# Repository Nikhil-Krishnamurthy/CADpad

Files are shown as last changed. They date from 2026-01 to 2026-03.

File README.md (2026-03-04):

# CADpad
Macropad designed from scratch for cad, media, and coding. Along with a custom script to run badapple on the oled screen!  
Note that the pcb has the scl and sca pins mixed up on it, I just cut the traces and ran a wire around it.  
  
Key Features  
Macropad with 11 reprogrammable keys  
oled screen that displays layers and animations  
rotary encoder that interfaces with computer  
interface with the computer for input and output  
And of course, it can run bad apple  

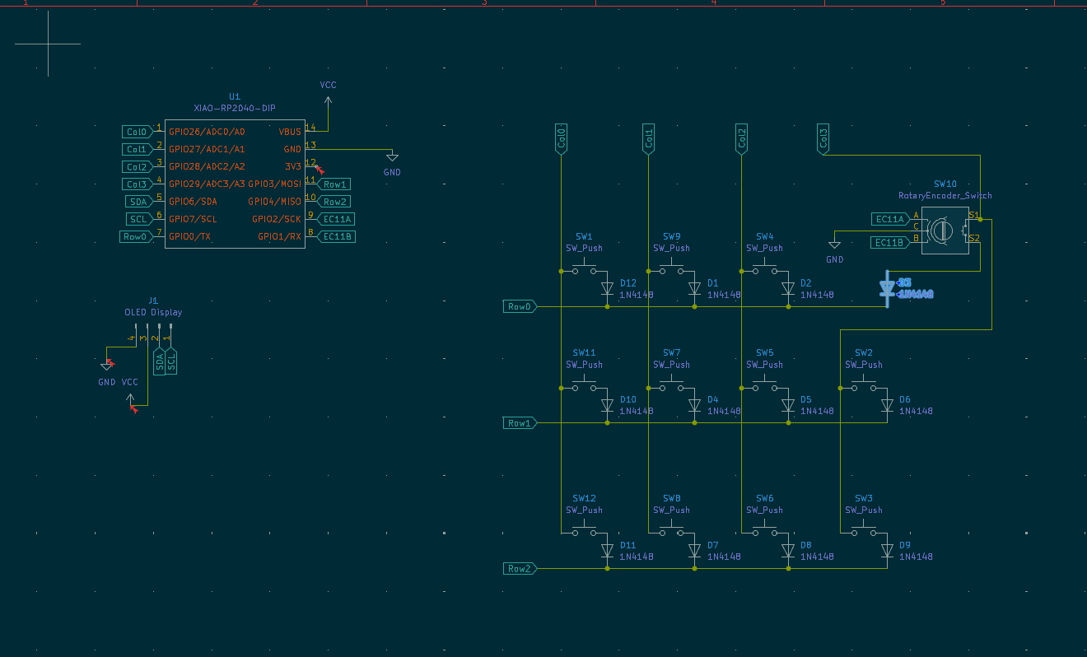
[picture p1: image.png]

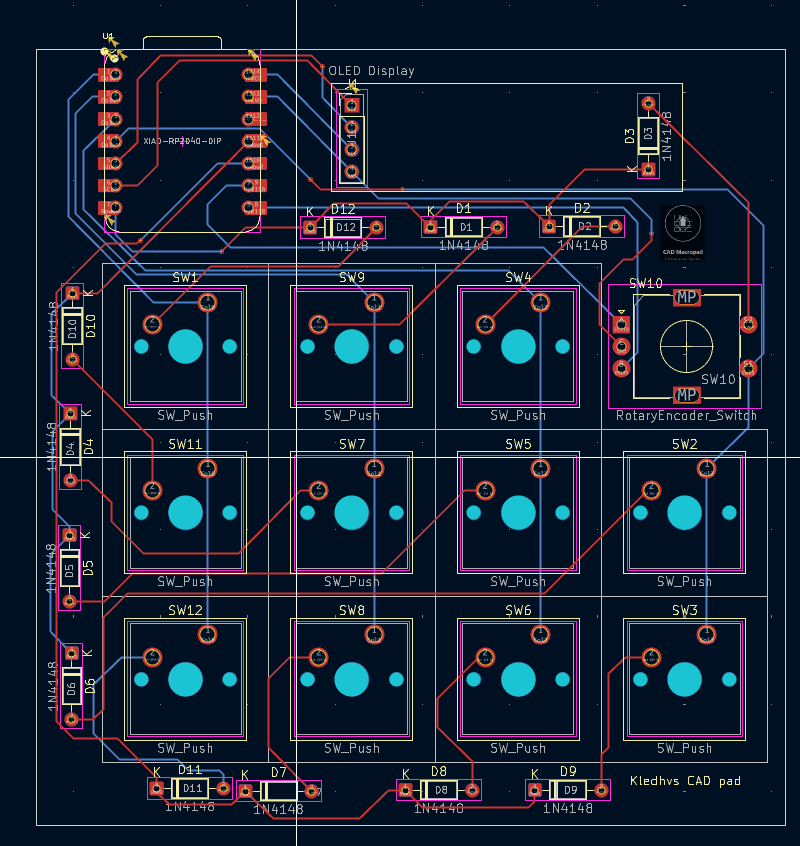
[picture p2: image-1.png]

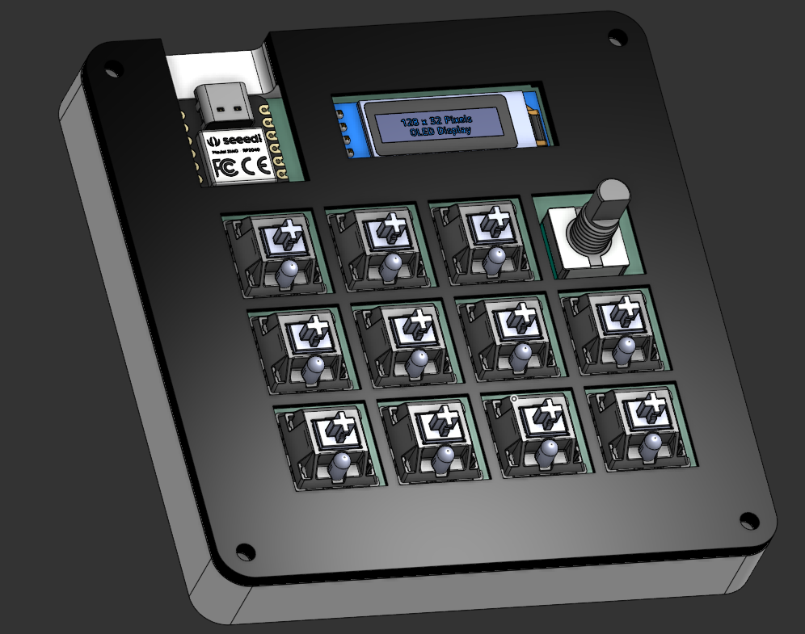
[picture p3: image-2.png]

BOM  
12x 1n4148 Diodes  
1x EC11 Encoders  
1x 0.91 in OLED display  
11x DSA keycaps  
11x Cherry MX Keycaps  
1x XIAO RP2040  
1X Case (3d Printed)  
4x M3 16mm screws  
4x M3x5mmx4mm Heat Inserts

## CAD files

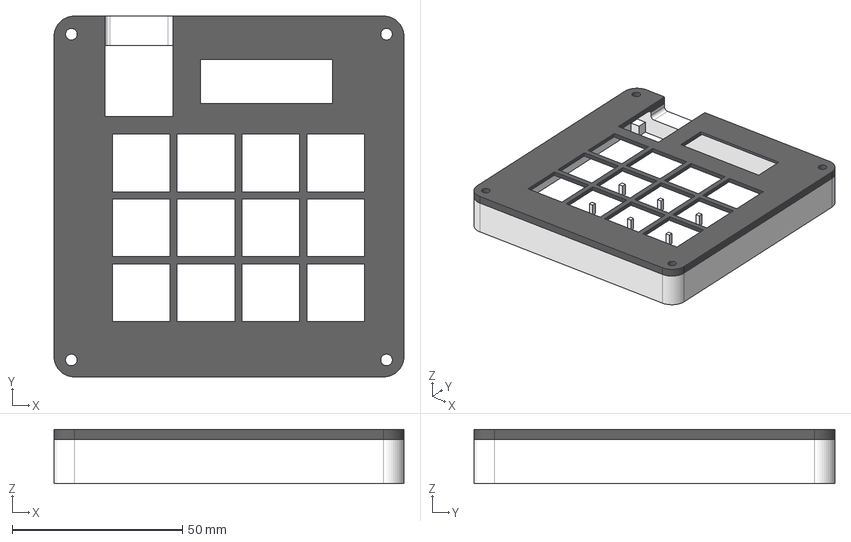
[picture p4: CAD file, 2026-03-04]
CAD/CadPad.step
102.8 x 106.0 x 16.0 mm

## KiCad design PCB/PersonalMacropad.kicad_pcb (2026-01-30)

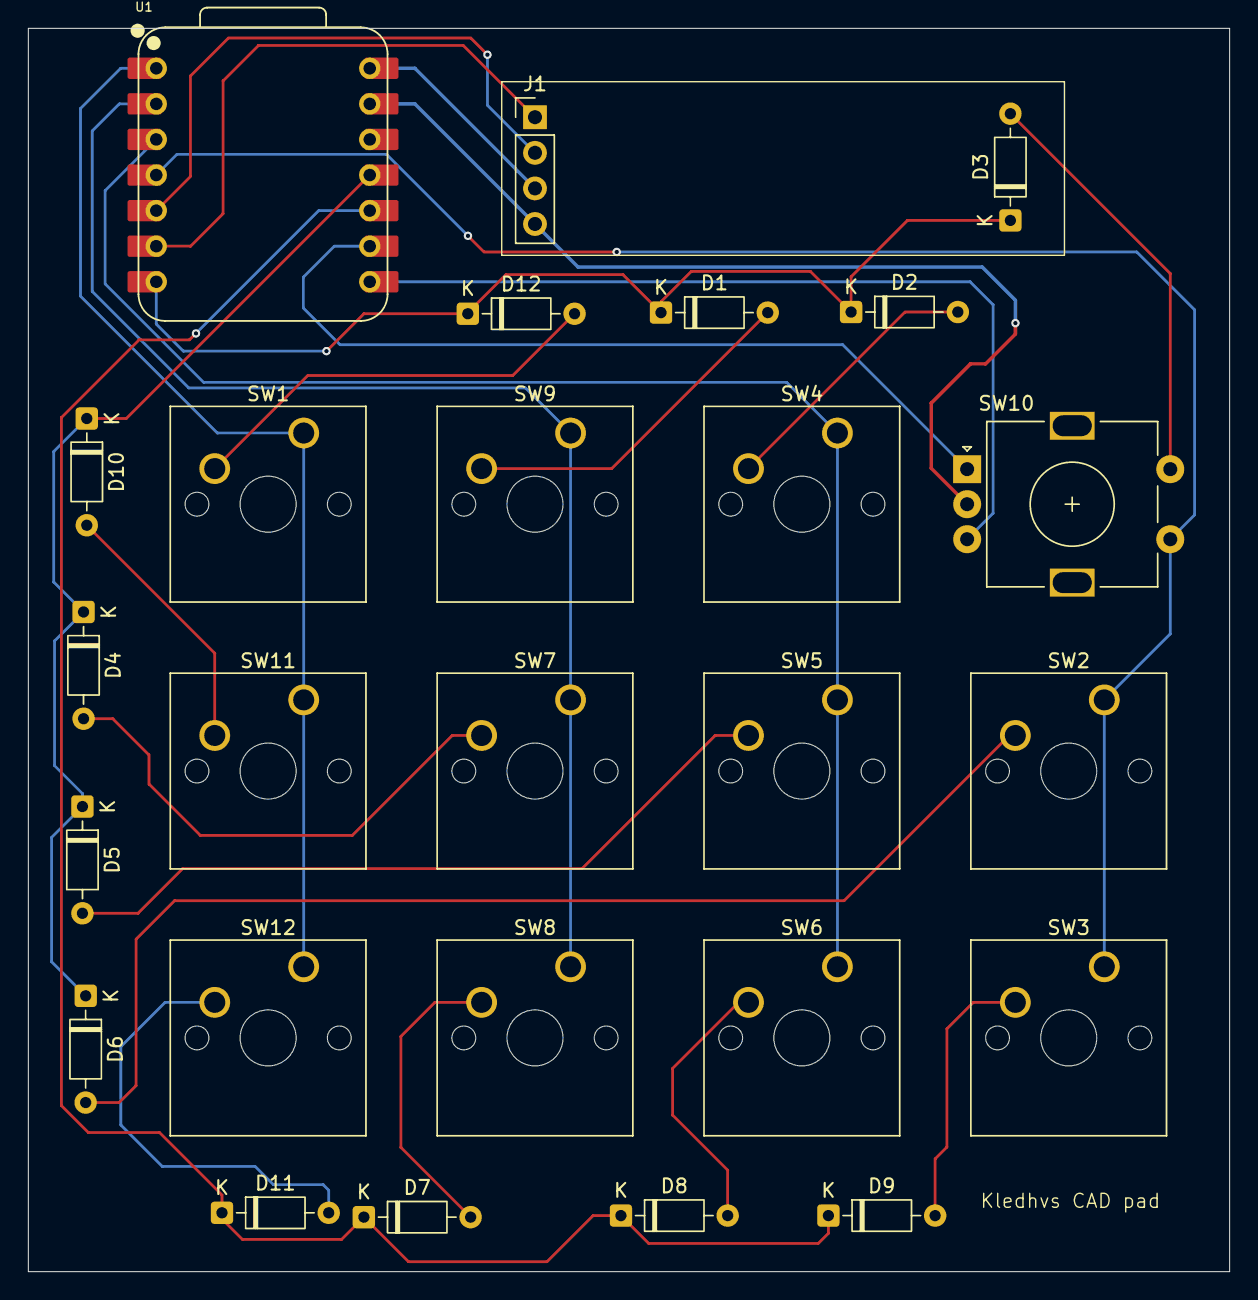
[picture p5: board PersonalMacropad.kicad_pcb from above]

Board: 2 copper layers, 85.7 x 88.8 mm, 26 parts (0 on the bottom side), 25 nets.

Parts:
D1, D2, D3, D4, D5, D6, D7, D8, D9, D10, D11, D12: 1N4148; D_DO-35_SOD27_P7.62mm_Horizontal
J1: OLED Display; PinHeader_1x04_P2.54mm_Vertical
SW1, SW2, SW3, SW4, SW5, SW6, SW7, SW8, SW9, SW11, SW12: SW_Push; SW_Cherry_MX_1.00u_PCB
SW10: RotaryEncoder_Switch; RotaryEncoder_Alps_EC11E-Switch_Vertical_H20mm
U1: XIAO-RP2040-DIP

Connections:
Col0: SW1.1, SW11.1, SW12.1, U1.1 (GPIO26/ADC0/A0)
Col1: SW7.1, SW8.1, SW9.1, U1.2 (GPIO27/ADC1/A1)
Col2: SW4.1, SW5.1, SW6.1, U1.3 (GPIO28/ADC2/A2)
Col3: SW2.1, SW3.1, SW10.S1, U1.4 (GPIO29/ADC3/A3)
EC11A: SW10.A, U1.9 (GPIO2/SCK)
EC11B: SW10.B, U1.8 (GPIO1/RX)
GND: J1.4, SW10.C, U1.13 (GND)
unnamed: D1.2 (A), SW9.2
unnamed: D2.2 (A), SW4.2
unnamed: D3.2 (A), SW10.S2
unnamed: D4.2 (A), SW7.2
unnamed: D5.2 (A), SW5.2
unnamed: D6.2 (A), SW2.2
unnamed: D7.2 (A), SW8.2
unnamed: D8.2 (A), SW6.2
unnamed: D9.2 (A), SW3.2
unnamed: D10.2 (A), SW11.2
unnamed: D11.2 (A), SW12.2
unnamed: D12.2 (A), SW1.2
Row0: D1.1 (K), D2.1 (K), D3.1 (K), D12.1 (K), U1.7 (GPIO0/TX)
Row1: D4.1 (K), D5.1 (K), D6.1 (K), D10.1 (K), U1.11 (GPIO3/MOSI)
Row2: D7.1 (K), D8.1 (K), D9.1 (K), D11.1 (K), U1.10 (GPIO4/MISO)
SCL: J1.1, U1.6 (GPIO7/SCL)
SDA: J1.2, U1.5 (GPIO6/SDA)
VCC: J1.3, U1.14 (VBUS)

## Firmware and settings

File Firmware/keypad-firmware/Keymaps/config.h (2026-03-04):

#pragma once

#define I2C_DRIVER I2CD1
#define I2C1_SDA_PIN GP6
#define I2C1_SCL_PIN GP7

#define OLED_BRIGHTNESS 90
#define OLED_TIMEOUT 5000
#define OLED_UPDATE_INTERVAL 100
#define OLED_DISPLAY_ADDRESS 0x3C
#define OLED_BOOT_TIMEOUT 100

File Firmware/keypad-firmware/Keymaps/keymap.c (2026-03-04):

// Copyright 2023 Nico Stuhlmueller (@ThePurox)
// SPDX-License-Identifier: GPL-2.0-or-later
#include QMK_KEYBOARD_H
#include <string.h>

#define LAYOUT_MACROPAD(\
  k00, k01, k02, k03, \
  k10, k11, k12, k13, \
  k20, k21, k22, k23\
) {\
  { k00, k01, k02, k03 }, \
  { k10, k11, k12, k13 }, \
  { k20, k21, k22, k23 }  \
}

enum layer_names{
    __MEDIA,
    __CAD,
    __OVERLAY,
    __CODE,
    __OLED,
};

#define COPY LCTL(KC_C)
#define PSTE LCTL(KC_V)
#define UNDO LCTL(KC_Z)

#define D_MUTE LCTL(KC_F13)
#define D_DEAF LCTL(KC_F14)
    
#define EXTRUDE LSFT(KC_E)
#define SKETCH LSFT(KC_S)
#define REVOLVE LSFT(KC_W)
#define FILLET LSFT(KC_F)
#define STEAM LSFT(KC_TAB)
#define DISCORD LSFT(KC_NUBS)

#define KILLER LCTL(LSFT(KC_ESC))
#define PERFORMANCE LCTL(KC_F3)

#define MAX_OLED_BRIGHTNESS 255
#define HIGH_OLED_BRIGHTNESS 130
#define MEDIUM_OLED_BRIGHTNESS 90
#define LOW_OLED_BRIGHTNESS 65
#define MIN_OLED_BRIGHTNESS 1

#define LAYER_CYCLE_START 0
#define LAYER_CYCLE_END 4

#define IMPORT_BIN(sect, file, sym) \
    asm(".section " #sect "\n" \
        ".balign 4\n" \
        ".global " #sym "\n" \
        #sym ":\n" \
        ".incbin \"" file "\"\n" \
        ".global _sizeof_" #sym "\n" \
        ".set _sizeof_" #sym ", . - " #sym "\n" \
        ".balign 4\n" \
        ".section \".text\"\n")

IMPORT_BIN(".rodata", "badapple.bin", badapple_data);

extern const uint8_t badapple_data[];
extern const char _sizeof_badapple_data[];

#define TOTAL_FRAMES 3194
#define FRAME_DELAY 100

static uint32_t oled_timer = 0;
static uint16_t frame_index = 0;

enum keycodes {
  KC_CYCLE_LAYERS = QK_USER,
  CK_CYCLE_LAYERS,
  ANIMATION_TOGGLE,
  OLED_BRIGHTNESS_UP,
  OLED_BRIGHTNESS_DOWN,
  OLED_BRIGHTNESS_DEFAULT,
  OLED_ON_OFF,
  ANIMATION_ONCE,
  PRINT_LN,
  PRINT,
  LOOP_STATEMENT,
  IF_STATEMENT,
  ELSE_IF_STATEMENT,
  ELSE_STATEMENT,
};

bool animation_value = false;
uint8_t loop_value = 0;
uint8_t brightness_layer = 2;

void brightness_picker(int level){
  switch(level){
    case 0:
      oled_set_brightness(MAX_OLED_BRIGHTNESS);
      break;
    case 1:
      oled_set_brightness(HIGH_OLED_BRIGHTNESS);
      break;
    case 2:
      oled_set_brightness(MEDIUM_OLED_BRIGHTNESS);
      break;
    case 3:
      oled_set_brightness(LOW_OLED_BRIGHTNESS);
      break;
    case 4:
      oled_set_brightness(MIN_OLED_BRIGHTNESS);
      break;
    default:
      break;
  }
}

void render_bad_apple(void) {
    if (timer_elapsed32(oled_timer) > FRAME_DELAY) {
        oled_timer = timer_read32();

        const uint8_t* frame_ptr = badapple_data + (frame_index * 512);

        // --- Fix 2: Added (const char*) cast to satisfy the compiler ---
        oled_write_raw_P((const char*)frame_ptr, 512);

        frame_index++;
        if (frame_index >= TOTAL_FRAMES) {
            frame_index = 0;
        }
    }
}

bool process_record_user(uint16_t keycode, keyrecord_t *record) {
  switch (keycode) {
    case KC_CYCLE_LAYERS: // Forward Cycle
      if (record->event.pressed) {
        uint8_t current_layer = get_highest_layer(layer_state);
        if (current_layer >= LAYER_CYCLE_START && current_layer <= LAYER_CYCLE_END) {
          uint8_t next_layer = current_layer + 1;
          if (next_layer > LAYER_CYCLE_END) {
              next_layer = LAYER_CYCLE_START;
          }
          layer_move(next_layer);
        }
      }
      return false;

    case CK_CYCLE_LAYERS: // Backward Cycle
      if (record->event.pressed) {
        uint8_t current_layer = get_highest_layer(layer_state);
        if (current_layer >= LAYER_CYCLE_START && current_layer <= LAYER_CYCLE_END) {
          uint8_t next_layer = current_layer - 1;
          if (next_layer < LAYER_CYCLE_START || next_layer > LAYER_CYCLE_END) { // Checks for underflow
              next_layer = LAYER_CYCLE_END;
          }
          layer_move(next_layer);
        }
      }
      return false;
    case ANIMATION_TOGGLE:
    if(record->event.pressed){  
    if(animation_value){
        animation_value = false;
        oled_timer = 0;
        frame_index = 0;
        oled_clear();
      }
      else{
        animation_value = true;
        oled_timer = 0;
        frame_index = 0;
      }
    }
      return false;
    
    case OLED_BRIGHTNESS_UP:
      if (record->event.pressed)
      {
      if(brightness_layer < 4){
        brightness_layer = brightness_layer + 1;
      }
      else if(brightness_layer == 4){
        brightness_layer = 0;
      }
      brightness_picker(brightness_layer);
    }
      return false;
    
    case OLED_BRIGHTNESS_DOWN:
      
    if(record->event.pressed){
      if(brightness_layer > 0){
        brightness_layer = brightness_layer - 1;
      }
      else if(brightness_layer == 0){
        brightness_layer = 4;
      }
      brightness_picker(brightness_layer);
    } 
      return false;
    
    case OLED_BRIGHTNESS_DEFAULT:
    if(record->event.pressed){  
    brightness_layer = 2;
      brightness_picker(brightness_layer);
    }
      return false;
    
    case OLED_ON_OFF:
      
    if(record->event.pressed){
      if(is_oled_on()){
        oled_off();
      }
      else{
        oled_on();
      }
      
    }
    return false;
    case PRINT_LN:
        if(record->event.pressed){
        SEND_STRING("System.out.println(");
        
        }
    return false;

    case IF_STATEMENT:
        if(record->event.pressed){
        SEND_STRING("if (){\n\n}");
        }
    return false;

    case ELSE_IF_STATEMENT:
        if(record->event.pressed){
        SEND_STRING("else if (){\n\n}");
        }
    return false;

    case ELSE_STATEMENT:
        if(record->event.pressed){
        SEND_STRING("else {\n\n}");
        }
    return false;

    case LOOP_STATEMENT:
        if(record->event.pressed){
        SEND_STRING("while (){\n\n}");
        }
    return false;

    case PRINT:
        if(record->event.pressed){
        SEND_STRING("System.out.print(");
        }
    return false;


    default:
      return true;
  }
}
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

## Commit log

2026-01-30 Uploaded Files
    Allows for others to use.
    [PersonalMacropad.kicad_pcb, PersonalMacropad.kicad_sch]
2026-03-04 New finished product
    [CadPad.step]
